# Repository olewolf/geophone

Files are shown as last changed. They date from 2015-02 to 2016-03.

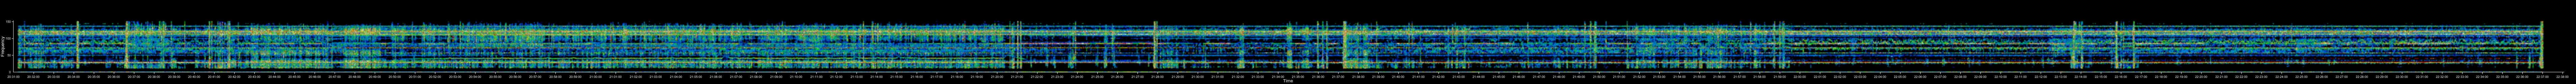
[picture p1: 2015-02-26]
heatmap.jpg

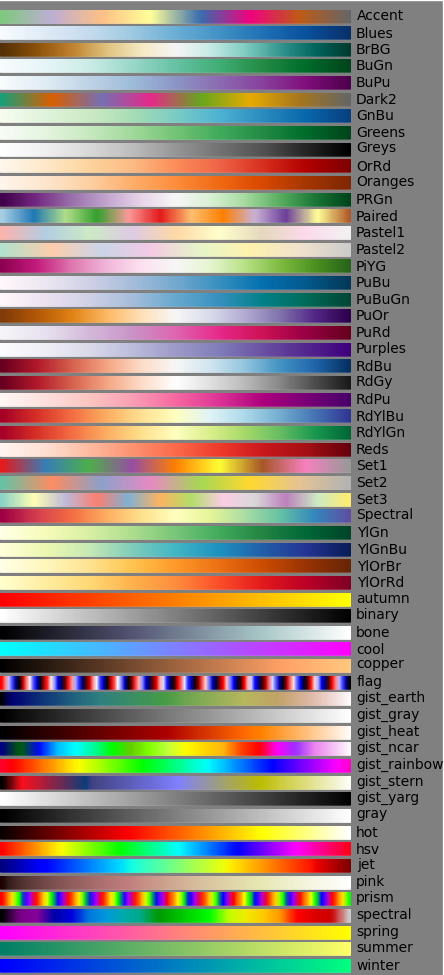
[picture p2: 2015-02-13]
bitbake-recipe/files/www/colormaps.png

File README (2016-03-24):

Geophone is an amplifier and a frequency analyzer for geometric sensors
such as the SM-24 geophone element from ION Geophysical Corp.

The amplifier is provided as an Arduino shield and the frequency analyzer is
implemented in software on the Arduino.  Because of the memory usage an
Arduino Mega or an Arduino Due is required.  Other Arduino versions with
at least 4 Kbytes of SRAM will require modifications in the code.

The Arduino code is richly commented and should be easy to understand and/or
modify.

For the Arduino Mega, use a single-supply operational amplifier capable of
working at 5V (such as an OP213) and set a jumper on JP3 to 5V mode.  For
the Arduino Due, use a single-supply operational amplifier working at 3.3V
(such as a TLC272 or an LT1215) to avoid damaging the Arduino's analog input.
JP3 should be placed in 3.3 mode.

Every second the Arduino software reports frequency components from 0 to 256
Hz and their measured amplitudes for amplitudes that exceed a programmed
threshold over the serial port.  The amplitudes are not calibrated; you will
have to perform a calibration yourself to translate the amplitudes into
ground movement in, e.g., meters per second.

The threshold may be changed by transmitting a new value followed by a
newline character.  The threshold is stored in EEPROM.

The frequency analysis lends itself directly to a 3D (or colored) time/
frequency plot that displays the intensities of different frequencies versus
time.  The Scilab script geoplot.sce reads a log file with the output and
generates such an image; geophone.log is a short sample of the output.

Geosampler.ino is a simple piece of software that samples the geophone
output at a rate of 512 samples per second and outputs the values over the
serial port.

read-serial-log.c provides sample C code that reads the serial output from
Geophone.ino and adds a timestamp.  The output may be plotted using the
createheatmap.pl perl script, which generates a JPEG file with the graphical
output.

Inquiries via the Github issue tracker, please.  This way, others may benefit
from the answers.

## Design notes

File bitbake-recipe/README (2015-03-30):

This directory contains files used to build the geophone analyzer on an
embedded system running Linux via the Open Embedded framework (see
<http://www.openembedded.org> for details on the framework).

The recipe sets up a sensor system that works as follows:

A daemon invoked via systemd continuously reads the Geophone output via
the USB serial port and writes a timestamped log to
/var/lib/geophone/geophone.log.  The log is rotated by logrotate.

Every 15 minutes a cron script creates a heatmap image based on the
geophone log data.  The heatmap image is placed in the web server directory
in /www/pages/geophone, and the previous heatmap image is renamed to
include a timestamp.  Heatmaps older than seven days are deleted.

The embedded Linux system runs a web server on its assigned IP address and
provides a simple heatmap viewer at http://<ip-address>/view-geophone-image.pl.

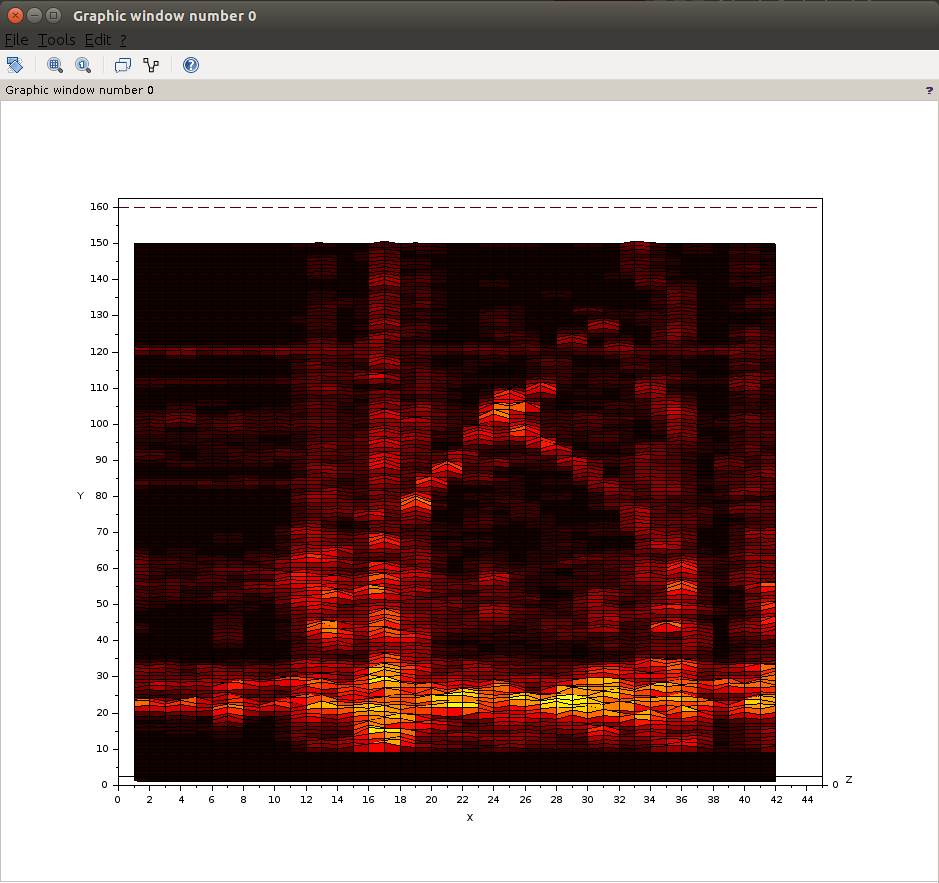
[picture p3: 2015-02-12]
sample-output.png

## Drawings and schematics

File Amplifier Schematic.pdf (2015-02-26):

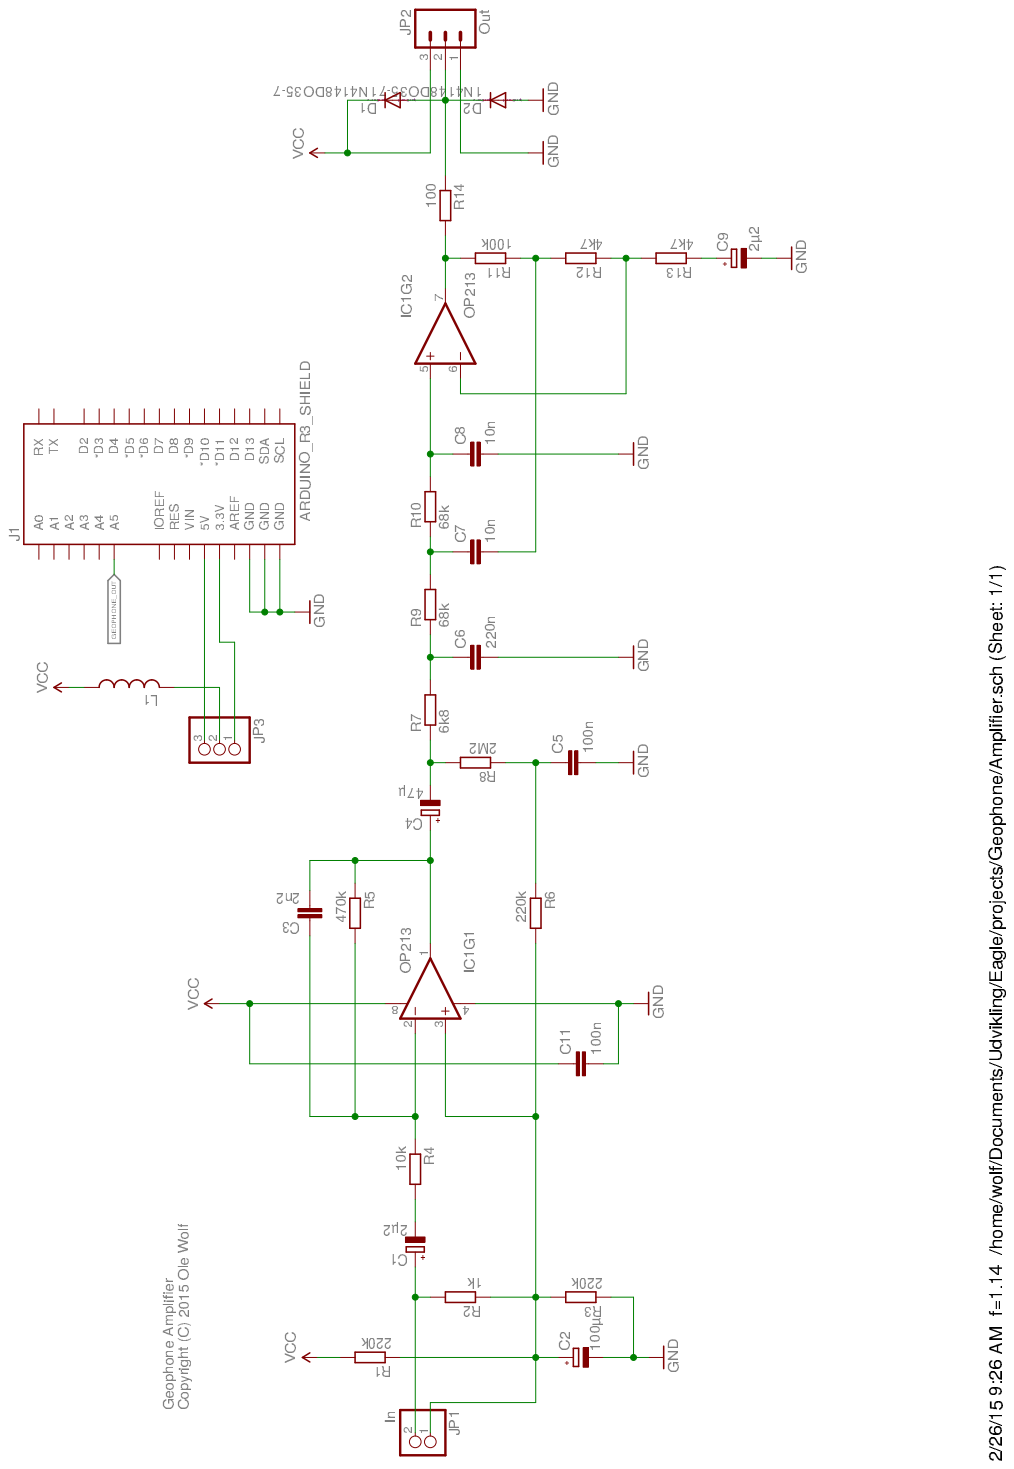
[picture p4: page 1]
⑧⑦q; ⑧⑦❶; ⑧⑦s❷; ⑧⑦ss; ⑦sr; ⑦sq; ❹❺❻; ④❼❽; ❸④❼❾; ❿❻⑦; q➀q❹; ➁❺④❼❾; ❽⑦❸; ❽➂➃; ➅➆➇➈➉➇➊➆; ➇➌➍

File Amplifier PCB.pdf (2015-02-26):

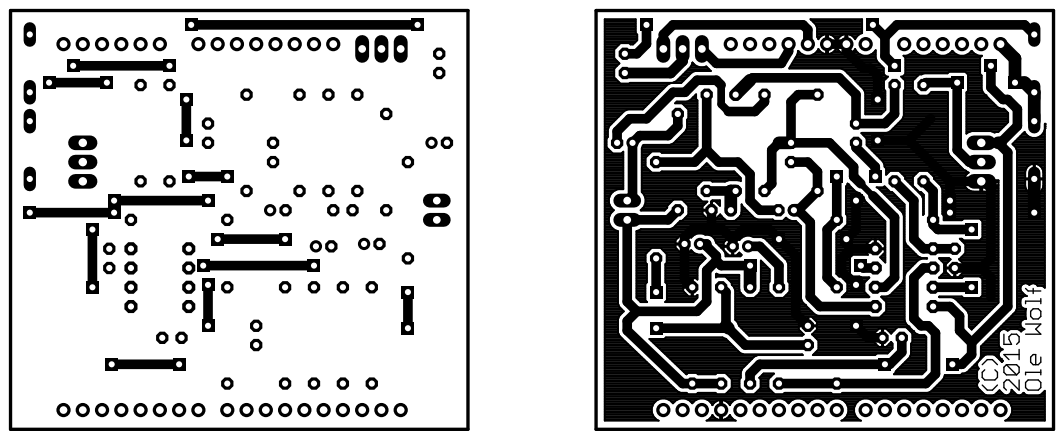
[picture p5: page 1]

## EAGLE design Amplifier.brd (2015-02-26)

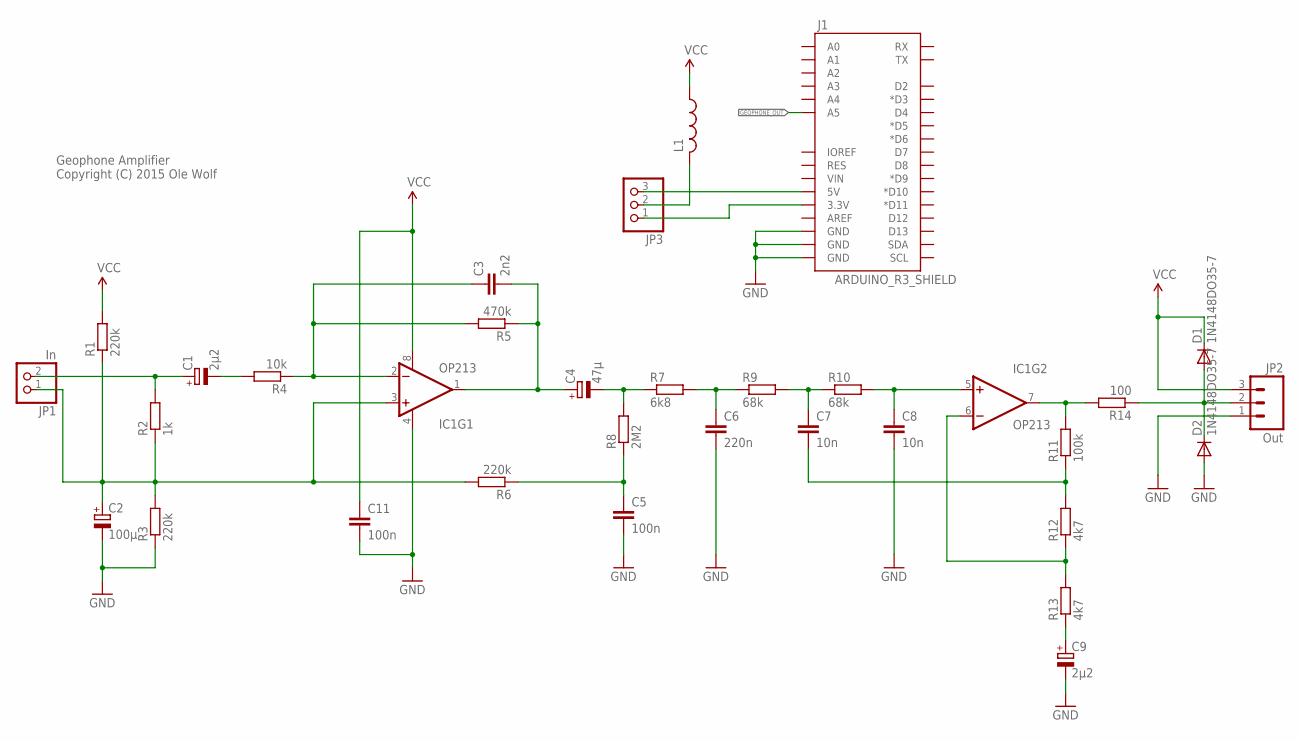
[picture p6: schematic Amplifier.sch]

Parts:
C1, C9: 2µ2; E2-5
C2: 100µ; E2-5
C3: 2n2; C025-025X050
C4: 47µ; E2-5
C5, C11: 100n; C025-025X050
C6: 220n; C025-025X050
C7, C8: 10n; C025-025X050
D1, D2: 1N4148DO35-7; DO35-7
IC1: OP213; DIP08
J1: ARDUINO_R3_SHIELD; UNO_R3_SHIELD
JP1: In; 1X02
JP2: Out; 1X03_LONGPADS
JP3: PINHD-1X3; 1X03
L1: L-US0207/2V; 0207/2V
R1, R3, R6: 220k; 0207/12
R2: 1k; 0207/12
R4: 10k; 0207/12
R5: 470k; 0207/12
R7: 6k8; 0207/12
R8: 2M2; 0207/12
R9, R10: 68k; 0207/12
R11: 100k; 0207/12
R12, R13: 4k7; 0207/12
R14: 100; 0207/12

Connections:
GEOPHONE_OUT: D1.A, D2.C, J1.A5, JP2.2, R14.1
GND: C2.-, C5.2, C6.2, C8.2, C9.-, C11.2, D2.A, IC1.4 (V-), J1.GND@0 (GND), J1.GND@1 (GND), J1.GND@2 (GND), JP2.1, R3.1
unnamed: C2.+, IC1.3 (+IN), JP1.1, R1.1, R2.1, R3.2, R6.2
unnamed: C1.-, R4.2
unnamed: C5.1, R6.1, R8.1
unnamed: C3.1, IC1.2 (-IN), R4.1, R5.2
unnamed: C1.+, JP1.2, R2.2
unnamed: C6.1, R7.2, R9.1
unnamed: JP3.2, L1.2
unnamed: IC1.6 (-IN), R12.1, R13.2
unnamed: C3.2, C4.+, IC1.1 (OUT), R5.1
unnamed: C4.-, R7.1, R8.2
unnamed: C7.1, R9.2, R10.1
unnamed: C9.+, R13.1
unnamed: C8.1, IC1.5 (+IN), R10.2
unnamed: J1.3.3V, JP3.1
unnamed: C7.2, R11.1, R12.2
unnamed: IC1.7 (OUT), R11.2, R14.2
unnamed: J1.5V, JP3.3
VCC: C11.1, D1.C, IC1.8 (V+), JP2.3, L1.1, R1.2

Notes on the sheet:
Geophone Amplifier Copyright (C) 2015 Ole Wolf

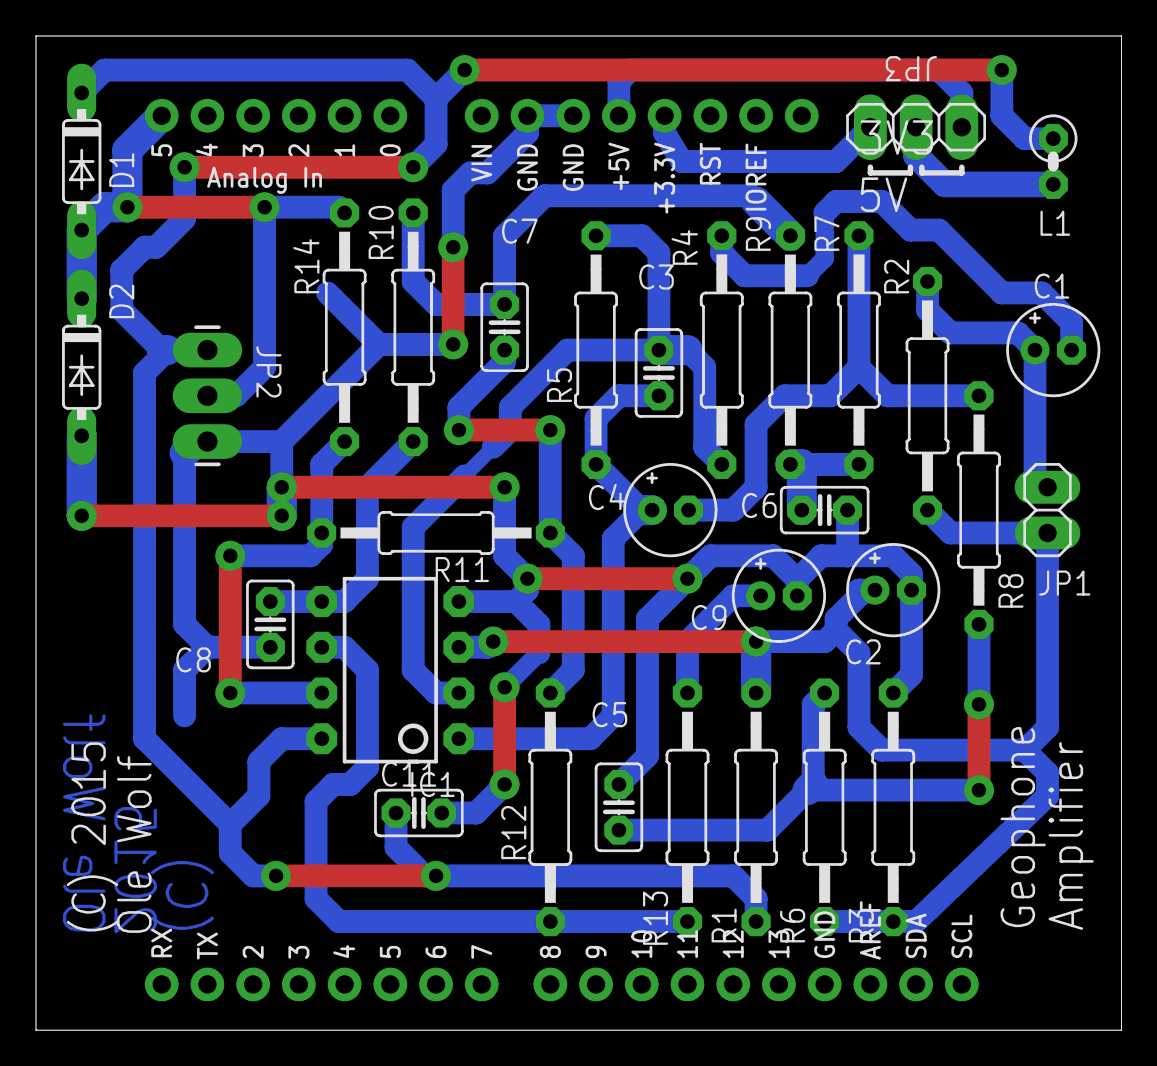
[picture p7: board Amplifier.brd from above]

Board: 2 copper layers, 60.3 x 55.2 mm, 32 parts (0 on the bottom side), 20 nets.

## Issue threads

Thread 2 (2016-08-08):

Hello! I have a question about using a geophone with your code.

wonchul-kim, 2016-08-08:
Dear olewolf,

This is Wonchul Kim who is a M.S. student at Seoul National Univ., Seoul, Korea.
During my project related to sensor-network, I am using SM-24 with your code.
I could understand geosampler.ino and now, I am working on geophone.ino.

In codes of geosampler.ino, I have a question.... please answer me....

I am very wondering why there needs sampling....
I know that analog signal should be sampled at a certain freq., but when I receive data from SM-24 by connecting it to analog pin on arduino mega board using 'analogRead(A0)', I could get data....

Could you exaplain it, please?

Thank you
Wonchul Kim

olewolf, 2016-08-21:
I'm not sure I understand your question. Reading data on an arduino using "analogRead" is in fact sampling the data. If you use this function at a certain frequency, then you're sampling at that frequency.

catox0, 2016-08-26:
Hello 김 원줄,

You can use analogRead(A#) to sample the signal.
But you need to read the analog signal at regular intervals, so the frequency analysis can rely on a well-defined time axis with equally spaced data points. The best (most reliable) way to control the timing of the analog read function is to use an internal timer of the Arduino. The timer counts a predefined number of clock cycles for the internal clock and can then directly trigger an analog-digital conversion (take a sample).

The section starting with   _/* Setup interrupts for the Arduino Mega. */_   (l.140ff) controls the timer and therefore sets up the sampling speed. You can look up the datasheet of the respective ATMEL chip to see how setting certain bits in control registers such as _TCCR1B_ will control the timer function.

I hope that helps.

Uttam1225, 2019-07-30:
Sir  Olewolf,

My name is Uttam Singh, I am currently working on project related to geophone(HG-24) connection with arduino uno, I have used your code geosampler.ino for blinking led on interrupt, keeping in mind with the same baud rate 115200 you mention in the code but it is not working out...can you help me in the same with the connection of LED, ARDUINO UNO and GEOPHONE(HG-24) or if i require any update in the code then please mention.

Waiting for your reply,
Uttam Singh

SismiWoolf, 2021-08-30:
Bonjours à tous, je cherchais mon compte gitHub, sur assistance d'accompagnement nocturne de troupeau domestique exposé aux predateurs naturels et ???
Enfin au sujet de l'Arduino, il y a lire et surtout pour la valeur l'enregistré dans une variable monCapteur = anologRead(A1), pour pouvoir la lire, on lira la valeur de la variable qui à pris l'échantillon de l'entrée analogique.... Oui s'est simple, là dans mon projet quelques grosse influences, utilisation d'arme chasse, materiel d'effarouchement, autres... Politique et moral detourné par politique de survaliste, liberté abusive, atteinte à la faune sauvage, detournement de technologie/d'objectif...
Compôrtement des predateurs naturels, de la faune (barrière d'activité exploité par les predateurs....
Oui l'objectif limité le surplus de tuerie, aucun appareil ne fonctionne, tout fonctionne à un taux d'efficacité sur le moment et aussi avec le temps. Oui sujet chaud bouillant, entre deux feux protecteur abusif et anti abusif.... J'essai d'avancé même si dans 5 ans...
J'utilise le shemas FT994K... Sur arduino uno lecture de 2 geophone et enregistrement sur SD 30-60 capture / seconde.

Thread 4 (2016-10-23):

Few questions about design

sselbe, 2016-10-23:
I was building this circuit on a breadboard and not the Arduino shield approach that you documented here.  If running on Mega, can you just leave out the diodes and just run the signal out similar to the DiscoverCircuits example you referenced? There was a 100n capacitor you added to yours, what was the purpose and is that necessary?

Also, if connecting to three geophones to get all three axis, would you just build three amps and connect each to different analog pins? Or is there a better approach to get the best sampling freq?

olewolf, 2016-10-24:
The diodes are there to protect the input of the Arduino but they aren't really necessary as long as the op-amp is powered with the same voltage as the Arduino can tolerate on its analog inputs. So, you'll probably be safe omitting the diodes.

I assume you're referring to capacitor C11. This is a decoupling capacitor that one should always place very close to the power supply pins on any IC. It helps reduce electrical noise.

It would probably be relatively straight-forward to design a multiplexer between three geophone inputs and thus have just one amplifier on one pin, but personally I'd just build three amplifiers and connect them to three pins. (Actually, I believe the Arduino multiplexes the analog inputs onto a single ADC internally.)

sselbe, 2016-10-24:
Great, thanks @olewolf. I actually did just build the three amps and will just connect to other analog inputs. I appreciate all the great documentation on this project.

Closed 2016-10-24.

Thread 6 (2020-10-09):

5v jumper label appears incorrect

neonascent, 2020-10-09:
It looks like the "5v" label is across the wrong pins for the PCB design.

olewolf, 2020-10-09:
Thanks. Hopefully it's just a visual thing. I'll look into it.

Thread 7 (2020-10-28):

Sample/Serial comms Noise

neonascent, 2020-10-28:
Hi Ole - I love the project, and really appreciate your time putting it all up!

I'm having some issues with noise from the system.  It's all harmonics of 60Hz, and I can't tell if it's electrical noise from the serial send every second, or possibly a sampling artifact?

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

It gets a bit less noisy if I use 12v power for the Arduino; maybe my capacitor choices are incorrect?

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

Any suggestions would be appreciated

neonascent, 2020-11-02:
Ah I have realized I have put an LED where there should be an inductor! But what value of inductor?  It's not labelled on Schematic or PCB file.

olewolf, 2020-11-02:
The inductor is just a coil intended to suppress noise. I'm relatively sure you omit the inductor (that is, just short it) so you can use JP3 to select 5V or 3.3V.

neonascent, 2020-11-05:
Thank Ole - I'd love to take advantage of a coil to suppress some noise, but I don't know what a good value would be.  What value would you suggest?

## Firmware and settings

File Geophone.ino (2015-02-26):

/****************************************************************************
 * geophone.ino
 *
 * Record geophone data and create a time vs. frequency profile.
 * The geophone data is sampled from the amplifier board and analyzed for'
 * frequency content by removing any frequency components whose magnitude
 * is below a threshold value.
 *
 * The analysis is provided as a time stamp (in plain text) followed by
 * binary frequency component pairs.  Each frequency component pair consists
 * of the frequency bin (0 through 255) and its corresponding amplitude
 * (-32767 through 32767).  An "XBee mode" setting changes the report to
 * a binary format of (split) packets for Digi's XBee API.
 *
 * The software requires an Arduino with at least 4096 bytes of RAM such as
 * the Arduino Mega or the Arduino Due.
 *
 * See the file COPYRIGHT for copyright details.  In addition, the bit-
 * reversal function is based on "Katja's homepage on sinusoids,
 * complex numbers and modulation" at <http://www.katjaas.nl/home/home.html>.
 ***************************************************************************/

#include <math.h>
#if defined( ARDUINO_AVR_MEGA2560 )
#include <EEPROM.h>
#endif



/* The geophone data is sampled on analog pin 5. */
#define GEODATA_PIN          5
/* Value for zero input, i.e., DC value, at the analog input. */
#define GEODATA_DC_OFFSET    159

/* Enable a human-readable report on the serial port. */
#define HUMAN_READABLE_REPORT_ENABLED  1

/* Select the serial port (Serial, Serial1, Serial2, etc.).  The plain
   serial port is for outputting the readable format of the report. */
#define SERIAL_PORT        Serial
/* Serial speed for the report generation.  It should be fast enough to
   allow several values to be passed per second.  A speed of 38,400 baud
   should suffice for worst case reports of about 2,300 bytes. */
#define SERIAL_SPEED       115200

/* If XBee is enabled, then a report is transmitted over the XBEE_SERIAL_PORT
   in a binary format in multiple packets with the following slightly
   compressed format:

   [ ReportID  { Frequency0 Amplitude0 }..{ FrequencyN AmplitudeN }  ]
      4              8         12       ..       8         12          (bits)

   Identical IDs indicate that packets are part of the same report. The end
   of a report is indicated by a frequency of 0 and no amplitude. */
#define XBEE_ENABLED        0
/* The XBee serial port is for outputting the report in a packed format
   and embedded in an XBee API frame. The serial port uses two stop bits
   because I recall reading this is necessary at speeds of 115200 baud and
   above. */
#define XBEE_SERIAL_PORT    Serial1
#define XBEE_SERIAL_SPEED   115200
#define XBEE_SERIAL_CONFIG  SERIAL_8N2
/* Pin used to reset the XBee at power-up because that appears to be
   necessary.  */
#define XBEE_RESET_PIN      51

/* XBee destination address for the report; in this case the XBee coordinator. */
#define XBEE_DESTINATION_ADDRESS_64  { 0x00, 0x00, 0x00, 0x00, 0x00, 0x00, 0x00, 0x00 }
#define XBEE_DESTINATION_ADDRESS_16  { 0xff, 0xfe }
/* An XBee payload size is 84, or 66 if the message is encrypted.  (Otherwise
   the payload will be fragmented but let's stay in control.) */
#define MAX_XBEE_PAYLOAD_SIZE        66
#define MAX_XBEE_FRAME_SIZE          110
/* Define a delay in milliseconds between packets sent to the XBee radio so that
   its serial port gets time to flush. */
#define XBEE_TRANSMIT_DELAY 100

/* Report only frequency components within the range of the geophone sensor
   and the amplifier's bandpass setting.  For example with an SM-24 geophone
   measuring the range between 10 Hz to 240 Hz and an amplifier with a band-
   pass filter from 7 Hz to 150 Hz, the range is 10 Hz to 150 Hz. */
#define LOWEST_FREQUENCY_REPORTED    10
#define HIGHEST_FREQUENCY_REPORTED  150

/* Make an LED blink on every successful report. The on-board LED may be used
   but in this case it's pin 52. */
#define REPORT_BLINK_ENABLED    1
#define REPORT_BLINK_LED_PIN   52

/* Default threshold for reporting amplitudes. */
#define DEFAULT_AMPLITUDE_THRESHOLD  0.1

/* Define the geophone data sampling rate. */
#define SAMPLE_RATE   512

/* Include bit-reversed twiddle factors for a 512-point radix-2 DIT FFT. */
#define NUMBER_OF_GEODATA_SAMPLES 512
#include "twiddle_factors_256_br.h"

/* Define the on-board LED so we can turn it off. */
#define LED_PIN             13

/* EEPROM address where the amplitude threshold is stored.  Sadly, the Arduino
   Due doesn't have EEPROM. */
#define AMPLITUDE_THRESHOLD_EEPROM_ADDRESS 0


/* Create a double buffer for geodata samples so that the frequency analysis
 * may be performed on one buffer while the other is being filled with samples.
 * The imaginary part requires only one buffer.
 */
short geodata_samples[ NUMBER_OF_GEODATA_SAMPLES * 2 ];
short *geodata_samples_real;
short geodata_samples_imag[ NUMBER_OF_GEODATA_SAMPLES ];
/* Indexes used by the interrupt service routine. */
int  isr_hamming_window_index;
int  isr_current_geodata_index;
/* Semaphor indicating that a frame of geophone samples is ready. */
bool geodata_buffer_full;
/* Current threshold at which amplitudes are reported. */
double amplitude_threshold;
/* Flag that indicates that a report with amplitude information was
   created.  It is used by the report LED blinking. */
bool report_was_created;


/**
 * Setup the timer interrupt and prepare the geodata sample buffers for
 * periodic sampling.  Timer1 is used to generate interrupts at a rate of
 * 512 Hz.
 *
 * This function is board specific; if other board than the Arduino Mega
 * or the Arduino Due are used the code must be updated.
 */
void start_sampling( )
{
  /* Prepare the buffer for sampling. */
  isr_hamming_window_index  = 0;
  isr_current_geodata_index = 0;
  geodata_buffer_full       = false;

  /* Setup interrupts for the Arduino Mega. */
#if defined( ARDUINO_AVR_MEGA2560 )
  // Set timer1 interrupt to sample at 512 Hz. */
  const unsigned short prescaling     = 1;
  const unsigned short match_register = F_CPU / ( prescaling * SAMPLE_RATE ) - 1;
  cli( );
  TCCR1B = ( TCCR1B & ~_BV(WGM13) ) | _BV(WGM12);
  TCCR1A = TCCR1A & ~( _BV(WGM11) | _BV(WGM10) );
  TCCR1B = ( TCCR1B & ~( _BV(CS12) | _BV(CS11) ) ) | _BV(CS10);
  OCR1A = match_register;
  TIMSK1 |= _BV(OCIE1A);
  sei( );

  /* Setup interrupts the Arduino Due. */
#elif defined( ARDUINO_SAM_DUE )
  /* Set a 12-bit resolutiong. */
  analogReadResolution( 12 );
  /* Disable write protect of PMC registers. */
  pmc_set_writeprotect( false );
  /* Enable the peripheral clock. */
  pmc_enable_periph_clk( TC3_IRQn );
  /* Configure the channel. */
  TC_Configure( TC1, 0, TC_CMR_WAVE | TC_CMR_WAVSEL_UP_RC | TC_CMR_TCCLKS_TIMER_CLOCK4 );
  uint32_t rc = VARIANT_MCK / 128 / SAMPLE_RATE;
  /* Setup the timer. */
  TC_SetRA( TC1, 0, rc / 2 );
  TC_SetRC( TC1, 0, rc );
  TC_Start( TC1, 0 );
  TC1->TC_CHANNEL[ 0 ].TC_IER = TC_IER_CPCS;
  TC1->TC_CHANNEL[ 0 ].TC_IDR = ~TC_IER_CPCS;
  NVIC_EnableIRQ( TC3_IRQn );
#else
#error Arduino board not supported by this software.
#endif
}



#if defined( ARDUINO_AVR_MEGA2560 )
/**
 * Interrupt service routine for Arduino Mega devices which invokes the
 * generic interrupt service routine.
 */
ISR( TIMER1_COMPA_vect )
{
  sampling_interrupt( );
}


#elif defined( ARDUINO_SAM_DUE )
/**
 * Interrupt service routine for Arduino Due devices which invokes the
 * generic interrupt service routine.
 */
void TC3_Handler( )
{
  TC_GetStatus( TC1, 0 );
  sampling_interrupt( );
}


#else
#error Arduino board not supported by this software.
#endif



/*
 * Interrupt service routine for sampling the geodata.  The geodata analog
 * pin is sampled at each invokation of the ISR.  If the buffer is full, a
 * pointer is passed to the main program and a semaphor is raised to indicate
 * that a new frame of samples is available, and future samples are written
 * to the other buffer.
 *
 * While not a sampling task, we take advantage of the timer interrupt to
 * blink the report LED if enabled.
 */
void sampling_interrupt( )
{
  /* Read a sample and store it in the geodata buffer.  Apply a Hamming
     window as we go along.  It involves a cos operation; the alternative
     is an array that should be fit into program memory. */
#if defined( ARDUINO_AVR_MEGA2560 )
  const int adc_resolution = 1024;
#elif defined( ARDUINO_SAM_DUE )
  const int adc_resolution = 4096;
#endif

  /* Read the geodata sample from the analog input. */
  short geodata_sample = analogRead( GEODATA_PIN )
                         - ( adc_resolution >> 1 ) - GEODATA_DC_OFFSET;
  /* Compute the Hamming window weight. */
  const double alpha = 0.54;
  const double beta  = 1.0 - alpha;
  const double N     = (double)( NUMBER_OF_GEODATA_SAMPLES - 1 );
  double hamming_window =
    alpha - beta * cos( 2.0 * M_PI * (double)isr_hamming_window_index / N );
  isr_hamming_window_index++;
  /* Scale the sample and apply the window weight. */
  double window = hamming_window;
  const int scale = window * 32768.0 / adc_resolution;
  geodata_sample = (short)( (double)geodata_sample * (double)scale );
  geodata_samples[ isr_current_geodata_index++ ] = geodata_sample;

  /* Raise a semaphor if the buffer is full and tell which buffer
     is active. */
  if ( isr_current_geodata_index == NUMBER_OF_GEODATA_SAMPLES )
  {
    /* The lower buffer has been filled. */
    geodata_samples_real     = &geodata_samples[ 0 ];
    isr_hamming_window_index = 0;
    geodata_buffer_full      = true;
  }
  else if ( isr_current_geodata_index == NUMBER_OF_GEODATA_SAMPLES * 2 )
  {
    /* The upper buffer has been filled. */
    geodata_samples_real      = &geodata_samples[ NUMBER_OF_GEODATA_SAMPLES ];
    isr_current_geodata_index = 0;
    isr_hamming_window_index  = 0;
    geodata_buffer_full       = true;
  }

  /* In the same interrupt routine, handle report LED blinking. */
  report_blink( REPORT_BLINK_ENABLED );
}



/**
 * Blink the report LED if it has been enabled.
 *
 * @param enabled @a true if report blinking has been enabled.
 */
void report_blink( bool enabled )
{
  static unsigned long timestamp;
  static bool          led_on = false;

  if ( enabled == true )
  {
    /* Turn on the LED and start a timer if a report was created. */
    if ( report_was_created == true )
    {
      report_was_created = false;
      /* Make it a rather short blink of just 75 ms. */
      timestamp = millis( ) + 75;
      digitalWrite( REPORT_BLINK_LED_PIN, HIGH );
      led_on = true;
    }
    /* Turn off the LED once the timer expires. */
    if ( led_on == true )
    {
      if ( millis( ) > timestamp )
      {
        digitalWrite( REPORT_BLINK_LED_PIN, LOW );
        led_on = false;
      }
    }
  }
}



/**
 * Compute the amplitude based on a real and an imaginary component.
 *
 * @param [in] real Real component.
 * @param [in] real Imaginary component.
 * @return Amplitude.
 */
double compute_amplitude( double real, double imaginary )
{
  double amplitude = sqrt( real * real + imaginary * imaginary );
  return ( amplitude );
}



/**
 * Swap two complex numbers in an array.
 *
 * @param [in] first Index of the first number.
 * @param [in] second Index of the other number.
 * @param [in,out] real Array of real components.
 * @param [in,out] imaginary Array of imaginary components.
 */
void swap( int first, int second, short *real, short *imaginary )
{
  short temp_r = real[ first ];
  real[ first ] = real[ second ];
  real[ second ] = temp_r;

  short temp_i = imaginary[ first ];
  imaginary[ first ] = imaginary[ second ];
  imaginary[ second ] = temp_i;
}



/**
 * Bit-reverse the elements in a complex array.
 *
 * @param [in,out] real Array of real components.
 * @param [in,out] imag Array of imaginary components.
 * @param [in] length Length of the array.
 */
void bit_reverse_complex( short *real, short *imag, int length )
{
  int N = length;

  int halfn  = N >> 1;
  int quartn = N >> 2;
  int nmin1  = N - 1;

  unsigned int forward = halfn;
  unsigned int rev     = 1;

  /* Start of bit-reversed permutation loop, N/4 iterations. */
  for ( int i = quartn; i; i-- )
  {
    /* Gray code generator for even values. */
    unsigned int nodd = ~i;                  // counting ones is easier
    int zeros;
    for ( zeros = 0; nodd & 1; zeros++ )
    {
      nodd >>= 1;   // find trailing zeros in i
    }
    forward ^= 2 << zeros;      // toggle one bit of forward
    rev     ^= quartn >> zeros; // toggle one bit of rev

    /* Swap even and ~even conditionally. */
    if ( forward < rev )
    {
      swap( forward, rev, real, imag );
      nodd = nmin1 ^ forward; // compute the bitwise negations
      unsigned int noddrev = nmin1 ^ rev;
      swap( nodd, noddrev, real, imag ); // swap bitwise-negated pairs
    }

    nodd = forward ^ 1;    // compute the odd values from the even
    unsigned int noddrev = rev ^ halfn;
    swap( nodd, noddrev, real, imag );  // swap odd unconditionally
  }
}



/**
 * Q.15  fractional integer 16-bit x 16-bit -> 16-bit multiplication.
 *
 * @param [in] a The first q.15 fractional integer factor.
 * @param [in] b The other q.15 fractional integer factor.
 * @return Product in q.15 fractional integer format.
 */
inline short q15_mul16( short a, short b )
{
  // Perform a 32-bit x 32-bit -> 32-bit integer multiplication.
  int32_t product = (int32_t)a * (int32_t)b;
  // Convert to q.15 fractional.
  return ( (short)( ( product >> 15 ) & 0x0000ffff ) );
}



/**
 * Complex addition using q.15 fractional arithmetic.
 *
 * @param [out] res_r Real part of complex sum.
 * @param [out] res_i Imaginary part of complex sum.
 * @param [in] r1 Real part of first complex number.
 * @param [in] i1 Imaginary part of first complex number.
 * @param [in] r2 Real part of second complex number.
 * @param [in] i2 Imaginary part of second complex number.
 */
inline void complex_add( short *res_r, short *res_i,
                         short r1, short i1, short r2, short i2 )
{
  *res_r = r1 + r2;
  *res_i = i1 + i2;
}



/**
 * Complex multiplication using q.15 fractional arithmetic.
 *
 * @param [out] res_r Real part of complex product.
 * @param [out] res_i Imaginary part of complex product.
 * @param [in] r1 Real part of first complex factor.
 * @param [in] i1 Imaginary part of first complex factor.
 * @param [in] r2 Real part of second complex factor.
 * @param [in] i2 Imaginary part of second complex factor.
 */
inline void complex_mul( short *res_r, short *res_i,
                         short r1, short i1, short r2, short i2 )
{
  *res_r = q15_mul16( r1, r2 ) - q15_mul16( i1, i2 );
  *res_i = q15_mul16( r1, i2 ) + q15_mul16( i1, r2 );
}



/**
 * Perform a 512-point radix-2 in-place DIT FFT using q.15 fractional
 * arithmetic.
 *
 * @param [in,out] data_real Array of real components of complex input/output.
 * @param [in,out] data_imag Array of imaginary components of complex
 *        input/output.
 */
void fft_radix2_512( short *data_real, short *data_imag )
{
  const int length = 512;

  int pairs_per_group  = length / 2;
  int wingspan         = length / 2;

  /* Divide and conquer. */
  for ( int stage = 1; stage < length; )
  {
    for ( int group = 0; group < stage; group++ )
    {
      /* Read the twiddle factors for the curent group. */
      short WR = pgm_read_word_near( twiddle_real + group );
      short WI = pgm_read_word_near( twiddle_imag + group );

      /* Calculate the positions of the butterflies in this group. */
      int lower = 2 * group * pairs_per_group;
      int upper = lower + pairs_per_group;

      /* Compute all the butterflies in the current group. */
      for ( int butterfly = lower; butterfly < upper; butterfly++ )
      {
        /* Compute one FFT butterfly. */
        short temp_r, temp_i;
        complex_mul( &temp_r, &temp_i, WR, WI,
                     data_real[ butterfly + wingspan ],
                     data_imag[ butterfly + wingspan ]);
        complex_add( &data_real[ butterfly + wingspan ],
                     &data_imag[ butterfly + wingspan ],
                     data_real[ butterfly ], data_imag[ butterfly ],
                     -temp_r, -temp_i );
        complex_add( &data_real[ butterfly ], &data_imag[ butterfly ],
                     data_real[ butterfly ], data_imag[ butterfly ],
                     temp_r, temp_i );
      }
    }

    pairs_per_group = pairs_per_group >> 1;
    stage           = stage << 1;
    wingspan        = wingspan >> 1;
  }
}



/**
 * Transmit a package via an XBee device in API mode.  The package
 * is embedded in a Transmit Request (type 0x10) frame.
 *
 * @param [in] payload Package to send via XBee.
 * @param [in] payload_size Number of bytes in the package.
 * @param [in] address_64 64-bit XBee destination address.
 * @param [in] address_16 16-bit XBee destination address.
 */
void transmit_xbee_payload( const unsigned char *payload,
                            int payload_size,
                            const unsigned char *address_64,
                            const unsigned char *address_16 )
{
  static unsigned char frame_id = 1;
  const int header_size = 1 + 2 + 1 + 1 + 8 + 2 + 1 + 1;
  unsigned char xbee_frame[ header_size ];
  int pos = 0;

  /* Compose the frame header for a transmit request (0x10). */
  xbee_frame[ pos++ ] = 0x7e;
  xbee_frame[ pos++ ] = ( ( header_size + payload_size - 3 ) >> 8 ) & 0x00ff;
  xbee_frame[ pos++ ] = ( header_size + payload_size - 3 ) & 0x00ff;
  xbee_frame[ pos++ ] = 0x10;
  /* Setup destination address and transmit options. */
  xbee_frame[ pos++ ] = frame_id;
  for ( int i = 0; i < 8; i++ )
  {
    xbee_frame[ pos++ ] = address_64[ i ];
  }
  xbee_frame[ pos++ ] = address_16[ 0 ];
  xbee_frame[ pos++ ] = address_16[ 1 ];
  /* Options:  retry/repair enabled, encryption enabled, no extended timeout. */
  xbee_frame[ pos++ ] = 0;
  xbee_frame[ pos++ ] = 0x20;

  /* Copy the payload header header to the XBee. */
  XBEE_SERIAL_PORT.write( xbee_frame, header_size );
  /* Copy the payload to the Xbee device. */
  XBEE_SERIAL_PORT.write( payload, payload_size );

  /* Compute the checksum for the payload header. */
  unsigned char checksum = 0x00;
  for ( int i = 3; i < header_size; i++ )
  {
    checksum += xbee_frame[ i ];
  }
  /* Compute the checksum for the payload. */
  for ( int i = 0; i < payload_size; i++ )
  {
    checksum += payload[ i ];
  }

  /* Copy the checksum to the XBee, completing the frame. */
  checksum = 0xff - checksum;
  XBEE_SERIAL_PORT.write( checksum );

  /* Advance to the next XBee frame. */
  frame_id = frame_id + 1;
  if ( frame_id == 0 )
  {
    frame_id = 1;
  }
}



/**
 * Append 8 bits in a buffer that is composed of 4-bit values.
 *
 * @param [in,out] buffer Buffer with 4-bit values.
 * @param [in] value The 8-bit value to append to the buffer.
 * @param [in] bitpos Current bit position in the buffer.
 * @return New bit position in the buffer.
 */
int append_8_bits( unsigned char *buffer, unsigned char value, int bitpos )
{
  /* Compute the byte position to insert the value. */
  int bytepos = bitpos >> 3;
  /* If byte-aligned, just copy the byte. */
  if ( bitpos == bytepos << 3 )
  {
    buffer[ bytepos ] = value;
  }
  else
  {
    unsigned char upper_nibble = ( value >> 4 ) & 0x0f;
    unsigned char lower_nibble = value << 4;
    buffer[ bytepos ]     |= upper_nibble;
    buffer[ bytepos + 1 ]  = lower_nibble;
  }
  return ( bitpos + 8 );
}
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
void loop()
{
  /* Analyze the geophone data once it's available. */
  if ( geodata_buffer_full == true )
  {
    /* Set the imaginary data values to 0 as this is a real-valued signal. */
    unsigned long *geodata_samples_imag_l = (unsigned long *)&geodata_samples_imag[ 0 ];
    for( int i = 0; i < NUMBER_OF_GEODATA_SAMPLES >> 1; i++ )
    {
      geodata_samples_imag_l[ i ] = 0ul;
    }
    /* Compute the Fourier transform in-place. */
    fft_radix2_512( geodata_samples_real, &geodata_samples_imag[ 0 ] );
    bit_reverse_complex( geodata_samples_real, &geodata_samples_imag[ 0 ],
                         NUMBER_OF_GEODATA_SAMPLES );
     /* Compute the amplitudes and report them in the same run.  Since
       the input data is real, the last half of the Fourier transform is
       is the complex conjugate of the first half and thus redundant.
       (This is why we bother to bit-reverse the Fourier-transformed
       data:  otherwise the redundant information would be spread out
       in the output data and we would have to use bit-reversed addressing
       to pick the non-redundant values from the array anyway.) */
    report( geodata_samples_real, &geodata_samples_imag[ 0 ],
            NUMBER_OF_GEODATA_SAMPLES / 2 + 1, amplitude_threshold );

    geodata_buffer_full = false;
  }

  /* Read any new threshold value that may be provided.  Update the threshold
     and write it to EEPROM if the value is valid. */
  double threshold = get_new_threshold( );
  if ( threshold > 0.0 )
  {
    save_amplitude_threshold_to_eeprom( threshold );
    amplitude_threshold = threshold;
  }
}

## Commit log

2015-02-12 Initial commit.
    [Amplifier.brd, Amplifier.sch]
2015-02-12 Sample output from Scilab added
2015-02-13 Perl script to generate a heatmap image added
2015-02-14 Simple audio sampler added
2015-02-14 Fast clearing of the imaginary buffer, interrupts for the Mega hopefully fixed.
    [Geophone.ino]
2015-02-14 Heatmap generator handles timestamped log (sample log file added, too).
2015-02-17 Arduino Mega functionality confirmed. Prepared for XBee serial (disabled via #define in code).
2015-02-17 PDF files for the schematic and PCB added
2015-02-17 Leftover from a test fixed.
    [Geophone.ino]
2015-02-17 Incoming XBee frame parsing seems to function.
2015-02-18 Hamming window disabled because it attenuates the data too much
    [Geophone.ino]
2015-02-25 XBee frame header bug fixed. First XBee frames successfully transmitted and received.
    [Geophone.ino]
2015-02-25 Stupid bug in output stage fixed
    [Amplifier.brd, Amplifier.sch]
2015-02-26 Bug in output stage fixed, redundant capacitor removed.
    [Amplifier.brd, Amplifier.sch]
2015-02-26 DC offset compensation added. Q.15 multiplication bug fixed.
    [Geophone.ino]
2015-02-26 Sample code for reading the serial output added.
2015-02-26 Two hours of real samples processed with read-serial-log and createheatmap.pl.
2015-03-06 Log filter script that selects a range of datestamps added.
2015-03-29 Date::Parse removed from filter-log.pl
2015-03-31 Appears to work on a proprietary AT91SAM9G25 based board
2015-04-03 Heatmap saved as PNG rather than JPEG.
2015-04-03 Minor bug fixes, LED indicator added. Imagemagick recipe removed.
2015-04-05 Watchdog added for a board where connman crashes every now and then.

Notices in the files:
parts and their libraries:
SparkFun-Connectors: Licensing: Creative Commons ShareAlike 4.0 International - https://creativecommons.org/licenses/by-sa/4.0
